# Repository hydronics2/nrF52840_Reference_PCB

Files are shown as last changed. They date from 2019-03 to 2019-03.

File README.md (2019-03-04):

# nrF52840_reference_PCB

This is a reference design for the nrF52840 for easy SWD programming and testing.  This layout uses the nrF52840 module from Raytek called the [MDBT50Q](http://www.raytac.com/upload/download_files/1bca545683ea4caf48e1ec796c09b9d9.pdf).
This PCB has been tested and it works!  This design relied heavily on the work of [Adafruit's feather board](https://www.adafruit.com/product/4062). I accidently ordered the -P1M version (PCB antenna). I think the -1M version chip antenna has slightly better range/performance.

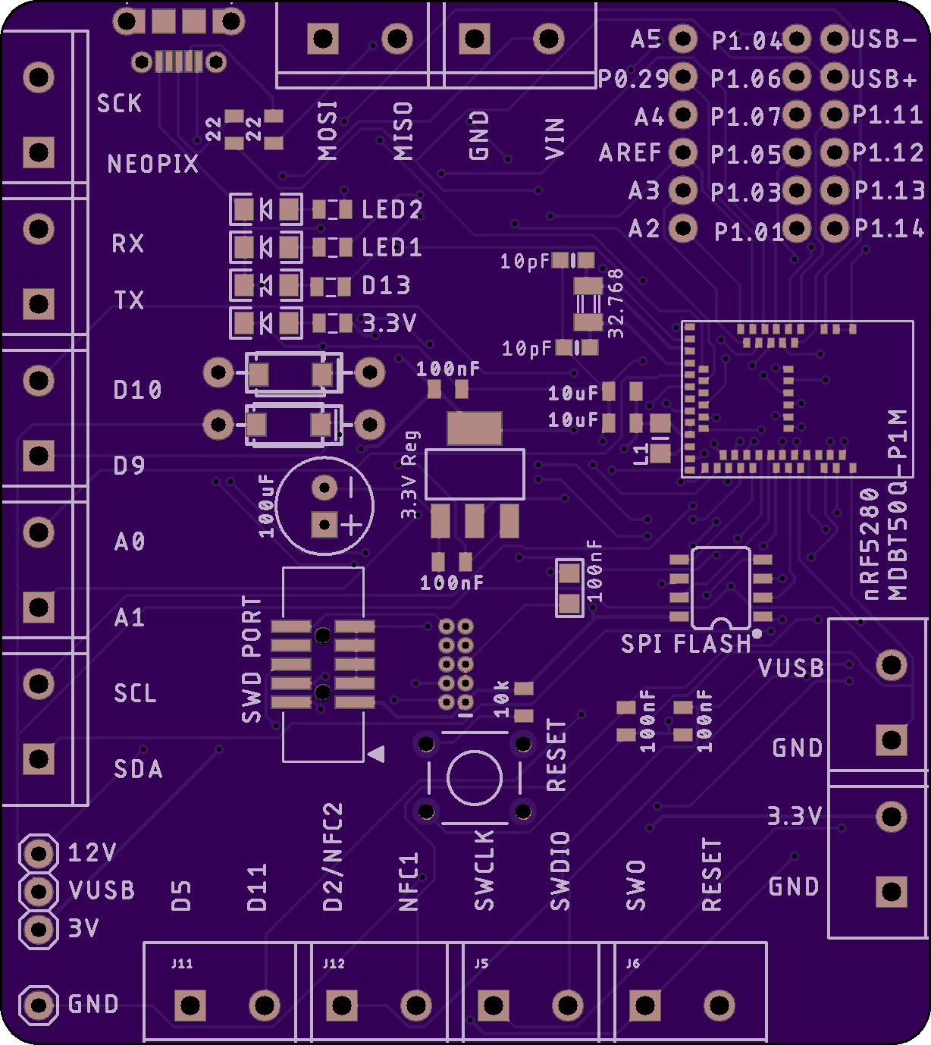
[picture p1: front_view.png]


I'm building an introduction class where I'd like to introduce students to soldering class, circuit python, and Internet of Things (IOT).  This module is also going to be a favorite for conference badges. This reference board is a good start. The changes from the feather are:
- broke out more pins
- changed the FLASH to an SOIC package
- changed some other packages slightly for easier soldering

You can order boards from Oshpark using this link: [project](https://oshpark.com/shared_projects/A5jKStz9).  

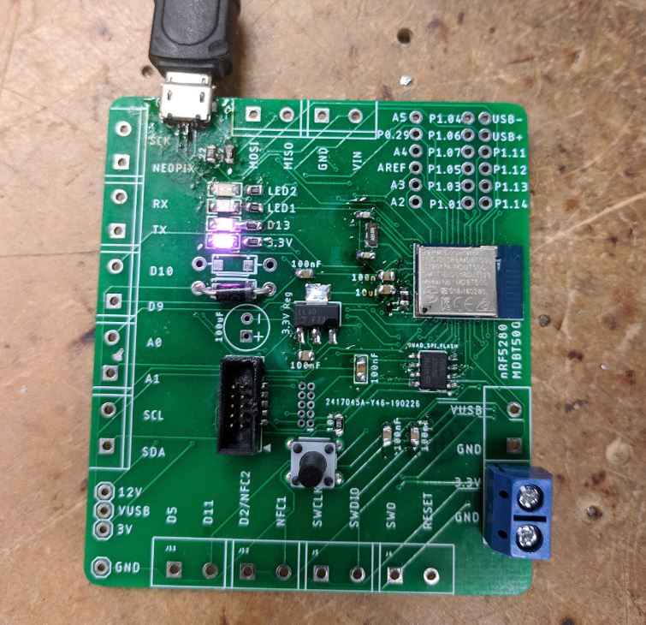
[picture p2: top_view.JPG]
project
This board has been tested and it works!! 

Here's a list of parts:

- MDBT50Q-P1M (PCB Antenna) from [digikey](https://www.digikey.com/product-detail/en/seeed-technology-co-ltd/113990583/1597-1679-ND/9697026). 
 or the MDBT50Q-1M (chip Antenna) from [digikey](https://www.digikey.com/product-detail/en/seeed-technology-co-ltd/113990584/1597-1680-ND/9697027)
- QUAD SPI Flash 2MB [digikey](https://www.digikey.com/product-detail/en/gigadevice-semiconductor-hk-limited/GD25Q16CTIGR/1970-1010-1-ND/9484760)
- 10 pin SWD Header from [digikey](https://www.digikey.com/product-detail/en/microchip-technology/ATSAMD21E15L-AFT/1611-ATSAMD21E15L-AFTCT-ND/6832779)
- 	Inductor 10UH  [digikey](https://www.digikey.com/product-detail/en/taiyo-yuden/LBR2012T100K/587-2045-1-ND/1788992)
- 3.3V Regulator (18V max input) [mouser](https://www.mouser.com/ProductDetail/511-LDL1117S50R)

- USB micro connector [digikey](https://www.digikey.com/product-detail/en/amphenol-icc-fci/10118194-0001LF/609-4618-1-ND/2785382)
- standard 6mmx6mm tactile RESET button [sparkfun](https://www.sparkfun.com/products/97)
- screw terminal 5mm pitch [sparkfun](https://www.sparkfun.com/products/8432) or [aliexpress](https://www.aliexpress.com/wholesale?catId=0&initiative_id=SB_20190221221755&SearchText=pcb+screw+terminal)
- input protection diodes on the 12V and USB input into the regulator. This is Adafruit's design. [digikey](https://www.digikey.com/product-detail/en/diodes-incorporated/B130-13-F/B130-FDICT-ND/815318)
- 32.768khz crystal (if needed, see above trinket design) [digikey](https://www.digikey.com/product-detail/en/epson/FC-135-32.7680KA-AG3/SER4086DKR-ND/6132726)
- crystal capacitors C7/C8 based on a 7pf load from the above crystal and assumed 2pf stray capacitence, CX1 = CX2 = 2(7pF - 2pF) = 10pF [digikey](https://www.digikey.com/product-detail/en/wurth-electronics-inc/885012006051/732-7793-1-ND/5454420)

SWD Programmer/Debugger: [Segger](https://www.digikey.com/product-detail/en/segger-microcontroller-systems/8.08.91-J-LINK-EDU-MINI/899-1061-ND/7387472)

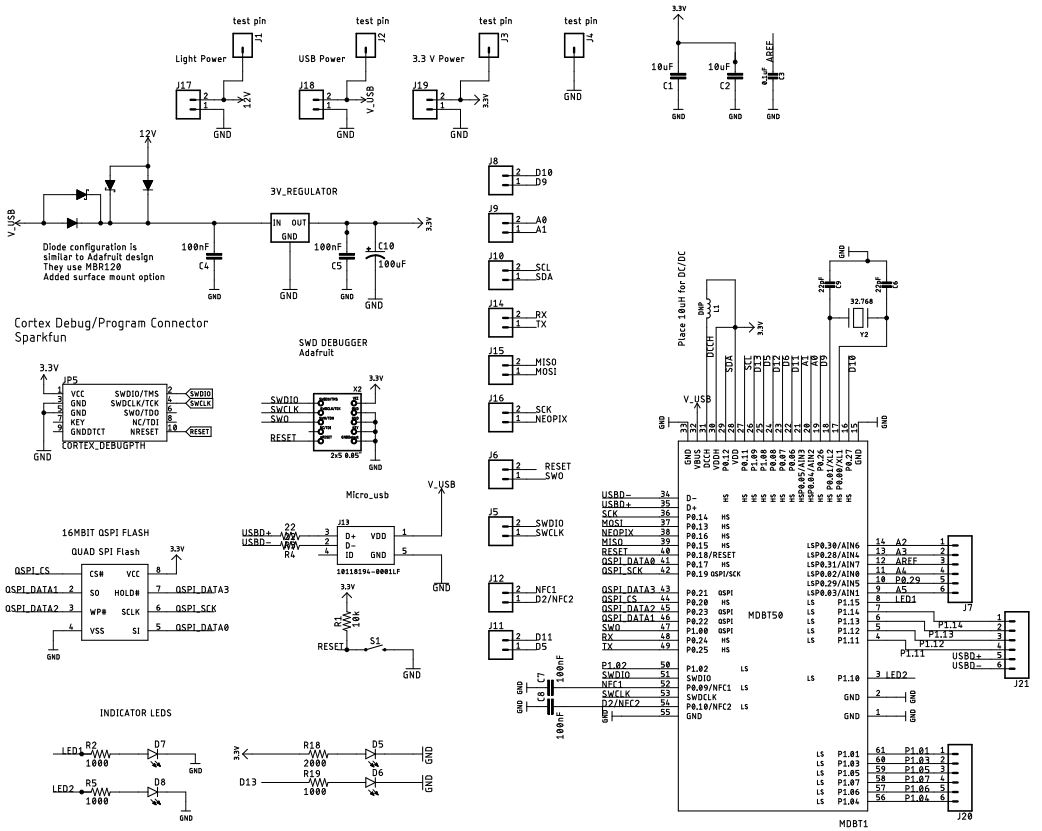
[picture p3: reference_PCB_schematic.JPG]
schematic


Notes:
- need to add a ground plane
- circuit python requires additional storage in the form of SPI Flash storage to hold files and libraries. For an extra $0.60 you can double to size of your flash to 4MB. Might be worth trying.

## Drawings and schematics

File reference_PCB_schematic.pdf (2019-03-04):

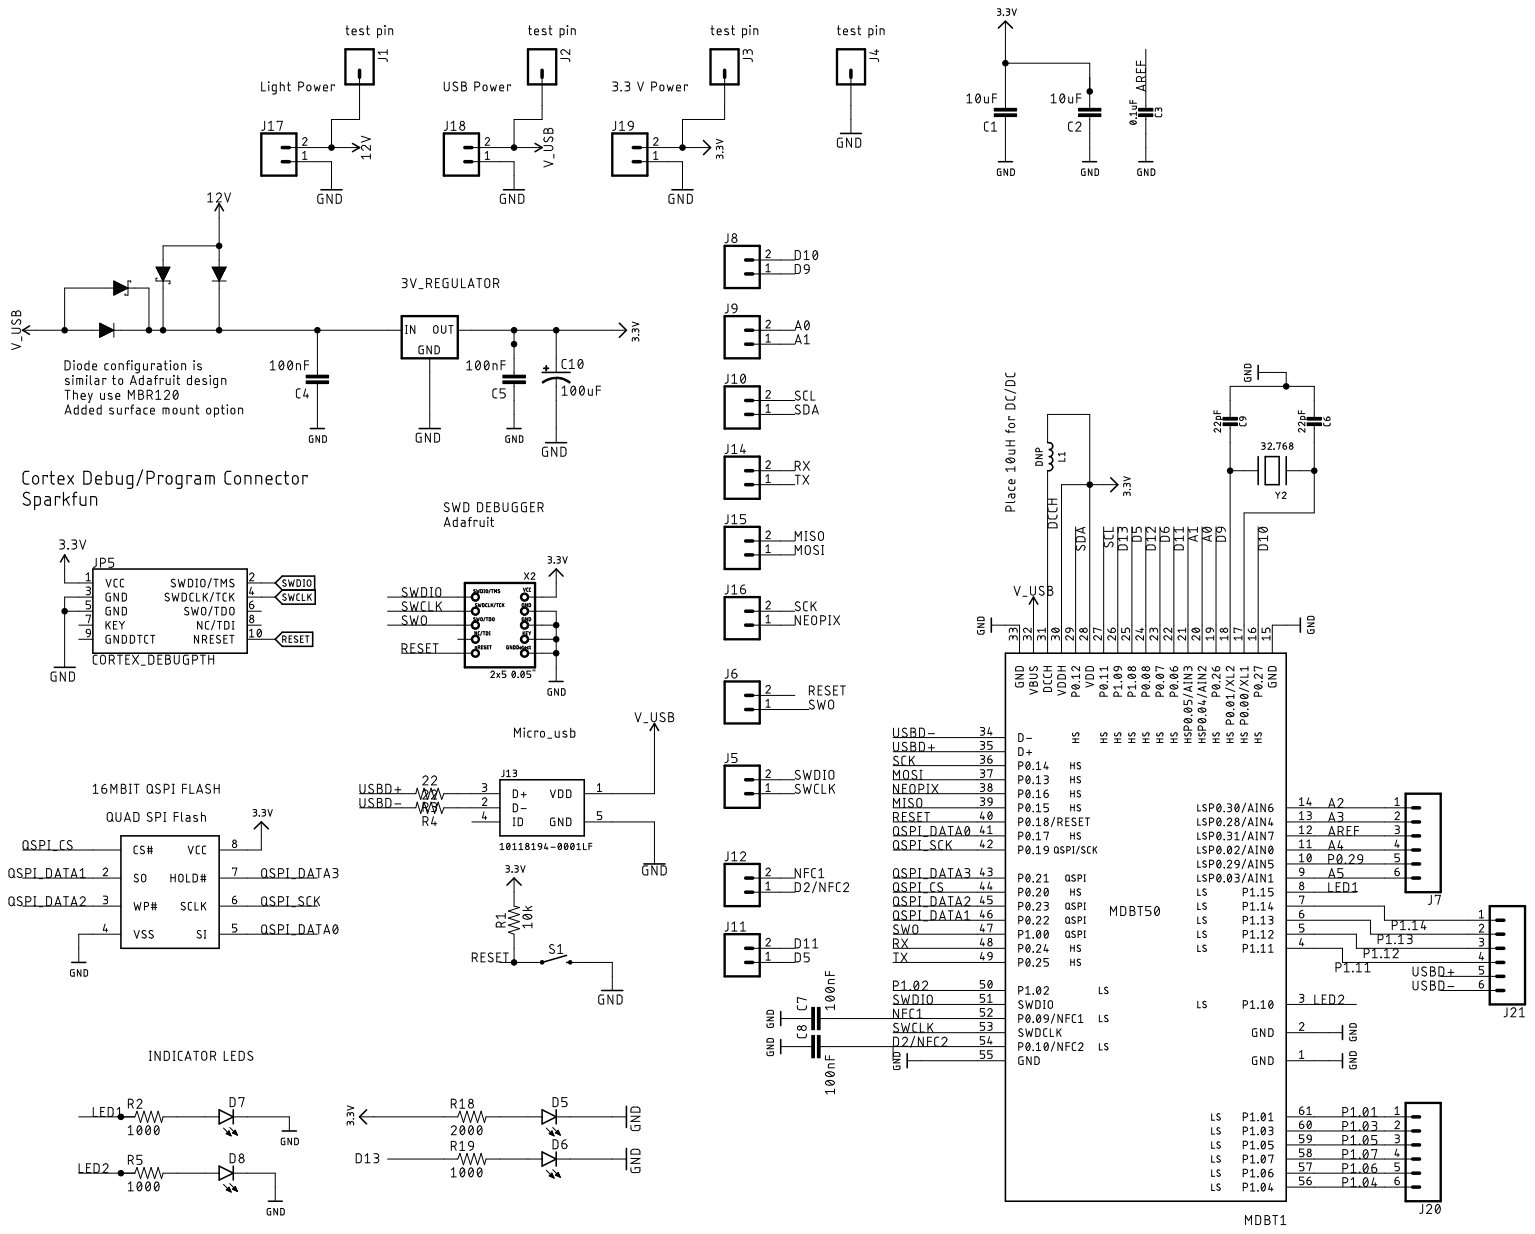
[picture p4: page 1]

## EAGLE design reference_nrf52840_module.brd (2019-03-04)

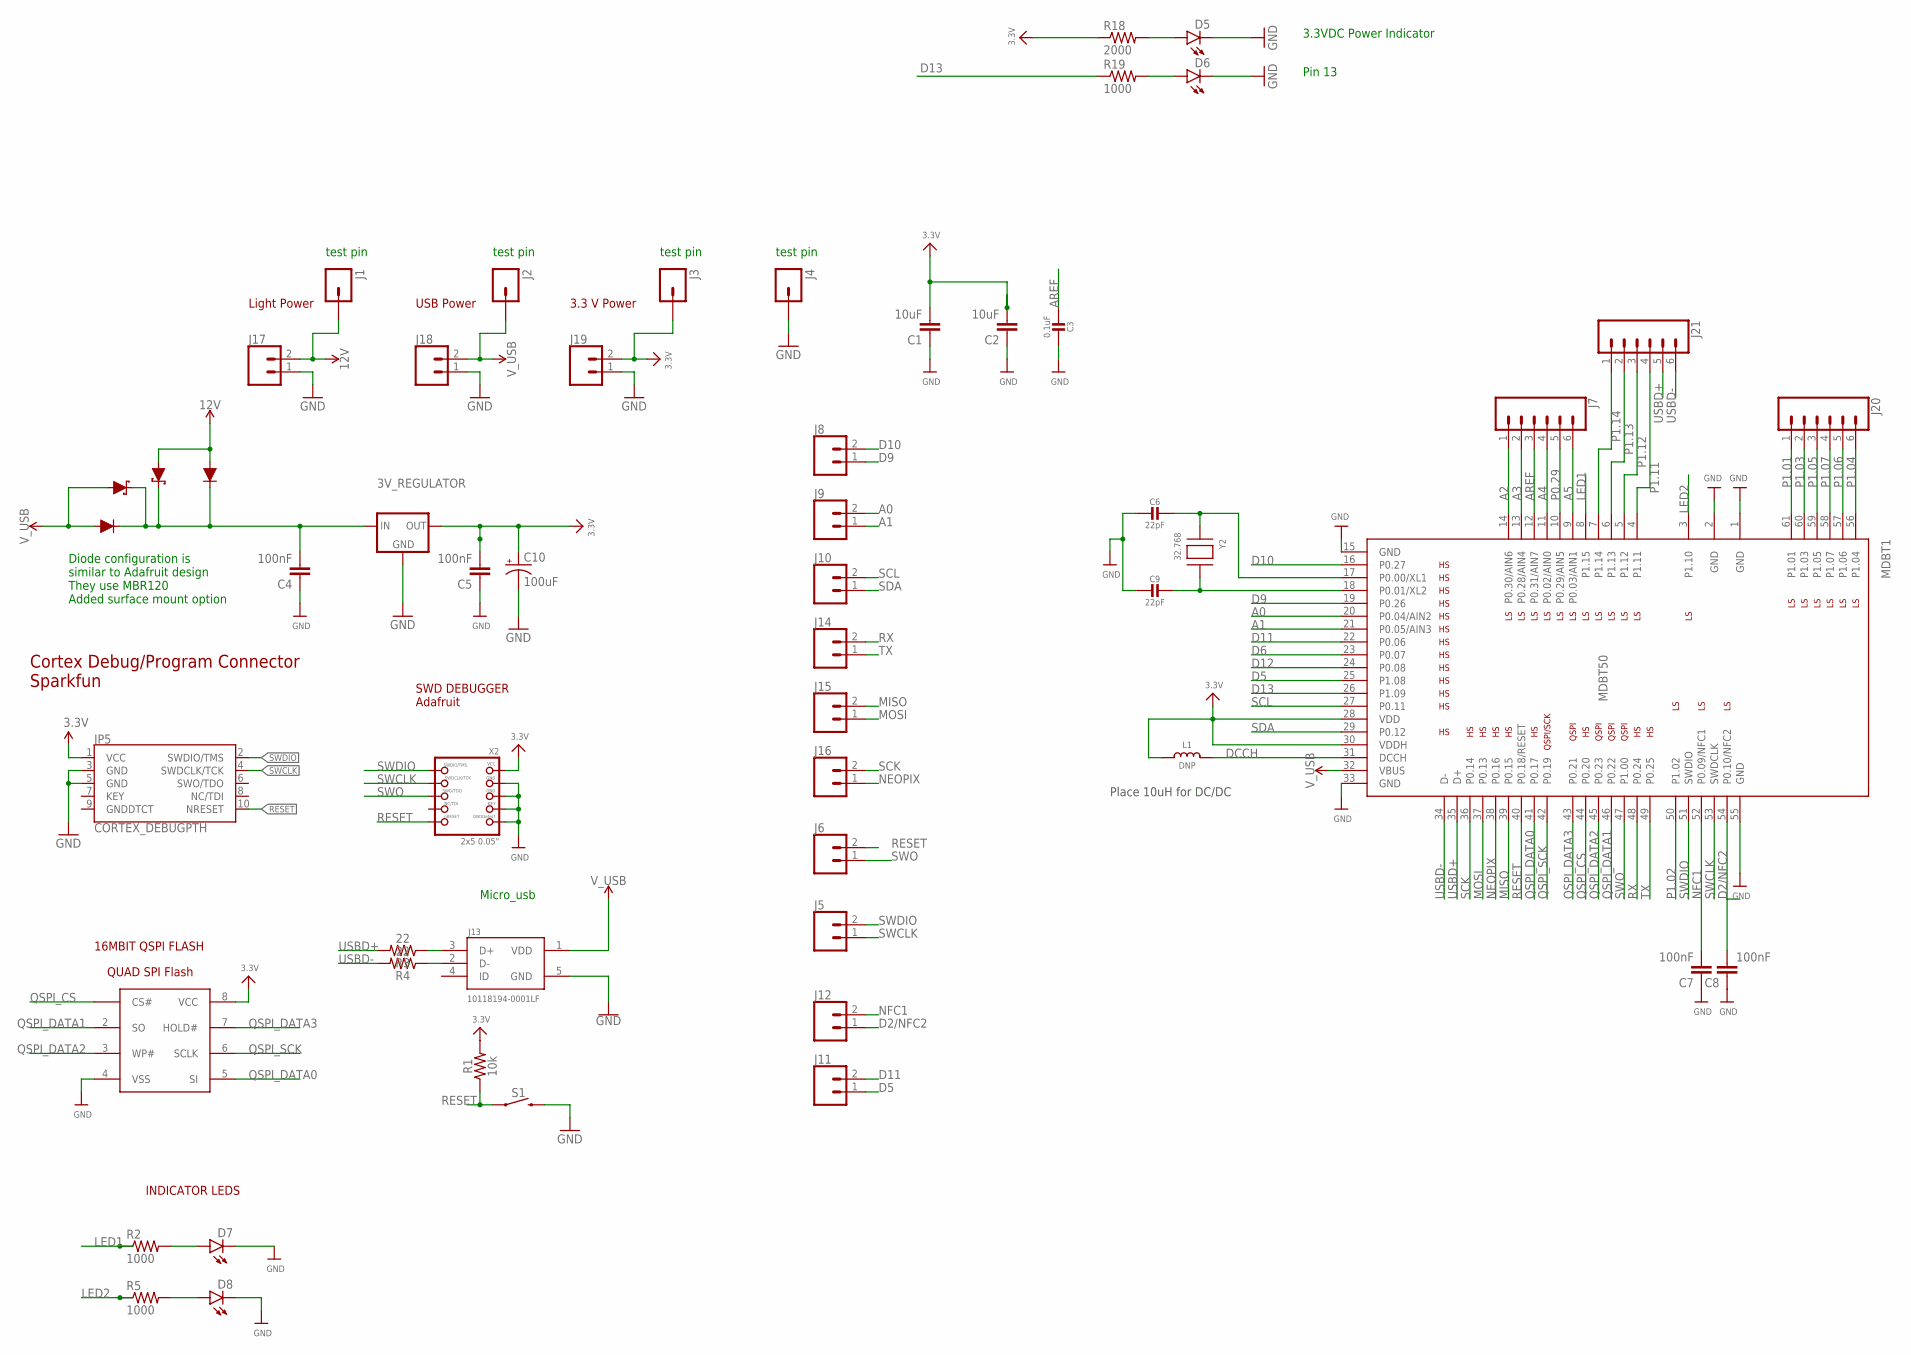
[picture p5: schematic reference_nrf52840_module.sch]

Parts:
3V_REGULATOR: LDL1117_5V_REG; SOT223
C1, C2: 10uF; 0805
C3: 0.1uF; _0805
C4, C5, C7, C8: 100nF; 0805
C6, C9: 22pF; 0603-NO
C10: 100uF; CPOL-RADIAL-2.5MM-6.5MM
D1, D2: 1A/50V/1.1V; DIODE-1N4001
D3, D4: 3A/40V/500mV; SMA-DIODE
D5, D6, D7, D8: LED1206; LED-1206
J1, J2, J3, J4: M01PTH; 1X01
J5, J6, J8, J9, J10, J11, J12, J14, J15, J16, J17, J18, J19: CONN_025MM; SCREWTERMINAL-5MM-2
J7, J20, J21: CONN_06NO_SILK_FEMALE_PTH; 1X06_NO_SILK
J13: 10118194-0001LF; FRAMATOME_10118194-0001LF
JP5: CORTEX_DEBUGPTH; 2X5-PTH-1.27MM
L1: DNP; _0805MP
MDBT1: MDBT50
R1: 10k; 0805
R2, R5, R19: 1000; 0805
R3, R4: 22; 0805
R18: 2000; 0805
S1: MOMENTARY-SWITCH-SPST-PTH-6.0MM-KIT; TACTILE_SWITCH_PTH_6.0MM_KIT
U$4: QUAD_SPI_FLASH; SO08
X2: 2x5 0.05"; 2X05_1.27MM_BOX_POSTS
Y2: 32.768; XTAL3215

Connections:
3.3V: 3V_REGULATOR.2 (OUT), 3V_REGULATOR.4 (OUT), C1.2, C2.2, C5.2, C10.1 (+), J3.1, J19.2, JP5.1 (VCC), L1.1, MDBT1.28 (VDD), MDBT1.30 (VDDH), R1.2, R18.1, U$4.8 (VCC), X2.1 (VCC)
12V: D1.A, D3.A, J1.1, J17.2
A0: J9.2, MDBT1.20 (P0.04/AIN2)
A1: J9.1, MDBT1.21 (P0.05/AIN3)
A2: J7.1, MDBT1.14 (P0.30/AIN6)
A3: J7.2, MDBT1.13 (P0.28/AIN4)
A4: J7.4, MDBT1.11 (P0.02/AIN0)
A5: J7.6, MDBT1.9 (P0.03/AIN1)
AREF: C3.2, J7.3, MDBT1.12 (P0.31/AIN7)
D2/NFC2: C8.2, J12.1, MDBT1.54 (P0.10/NFC2)
D5: J11.1, MDBT1.25 (P1.08)
D6: MDBT1.23 (P0.07)
D9: J8.1, MDBT1.19 (P0.26)
D10: J8.2, MDBT1.16 (P0.27)
D11: J11.2, MDBT1.22 (P0.06)
D12: MDBT1.24 (P0.08)
D13: MDBT1.26 (P1.09), R19.1
DCCH: L1.2, MDBT1.31 (DCCH)
GND: 3V_REGULATOR.1 (GND), C1.1, C2.1, C3.1, C4.1, C5.1, C6.2, C7.1, C8.1, C9.2, C10.2 (-), D5.C, D6.C, D7.C, D8.C, J4.1, J13.5 (GND), J17.1, J18.1, J19.1, JP5.3 (GND), JP5.5 (GND), MDBT1.1 (GND), MDBT1.2 (GND), MDBT1.15 (GND), MDBT1.33 (GND), MDBT1.55 (GND), S1.3 (2), U$4.4 (VSS), X2.3 (GND), X2.5 (GND), X2.7 (KEY), X2.9 (GNDDETECT)
LED1: MDBT1.8 (P1.15), R2.1
LED2: MDBT1.3 (P1.10), R5.1
MISO: J15.2, MDBT1.39 (P0.15)
MOSI: J15.1, MDBT1.37 (P0.13)
unnamed: D7.A, R2.2
unnamed: J13.3 (D+), R3.1
unnamed: J13.2 (D-), R4.1
unnamed: 3V_REGULATOR.3 (IN), C4.2, D1.C, D2.C, D3.C, D4.C
unnamed: C9.1, MDBT1.18 (P0.01/XL2), Y2.P$2
unnamed: C6.1, MDBT1.17 (P0.00/XL1), Y2.P$1
unnamed: D8.A, R5.2
unnamed: D5.A, R18.2
unnamed: D6.A, R19.2
NEOPIX: J16.1, MDBT1.38 (P0.16)
NFC1: C7.2, J12.2, MDBT1.52 (P0.09/NFC1)
P0.29: J7.5, MDBT1.10 (P0.29/AIN5)
P1.01: J20.1, MDBT1.61 (P1.01)
P1.02: MDBT1.50 (P1.02)
P1.03: J20.2, MDBT1.60 (P1.03)
P1.04: J20.6, MDBT1.56 (P1.04)
P1.05: J20.3, MDBT1.59 (P1.05)
P1.06: J20.5, MDBT1.57 (P1.06)
P1.07: J20.4, MDBT1.58 (P1.07)
P1.11: J21.4, MDBT1.4 (P1.11)
P1.12: J21.3, MDBT1.5 (P1.12)
P1.13: J21.2, MDBT1.6 (P1.13)
P1.14: J21.1, MDBT1.7 (P1.14)
QSPI_CS: MDBT1.44 (P0.20), U$4.1 (CS#)
QSPI_DATA0: MDBT1.41 (P0.17), U$4.5 (SI)
QSPI_DATA1: MDBT1.46 (P0.22), U$4.2 (SO)
QSPI_DATA2: MDBT1.45 (P0.23), U$4.3 (WP#)
QSPI_DATA3: MDBT1.43 (P0.21), U$4.7 (HOLD#)
QSPI_SCK: MDBT1.42 (P0.19), U$4.6 (SCLK)
RESET: J6.2, JP5.10 (NRESET), MDBT1.40 (P0.18/RESET), R1.1, S1.1, X2.10 (NRESET)
RX: J14.2, MDBT1.48 (P0.24)
SCK: J16.2, MDBT1.36 (P0.14)
SCL: J10.2, MDBT1.27 (P0.11)
SDA: J10.1, MDBT1.29 (P0.12)
SWCLK: J5.1, JP5.4 (SWDCLK/TCK), MDBT1.53 (SWDCLK), X2.4 (SWDCLK)
SWDIO: J5.2, JP5.2 (SWDIO/TMS), MDBT1.51 (SWDIO), X2.2 (SWDIO)
SWO: J6.1, MDBT1.47 (P1.00), X2.6 (SWO)
TX: J14.1, MDBT1.49 (P0.25)
USBD+: J21.5, MDBT1.35 (D+), R3.2
USBD-: J21.6, MDBT1.34 (D-), R4.2
V_USB: D2.A, D4.A, J2.1, J13.1 (VDD), J18.2, MDBT1.32 (VBUS)

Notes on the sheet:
SWD DEBUGGER Adafruit
Cortex Debug/Program Connector Sparkfun
Micro_usb
Light Power
USB Power
3.3 V Power
Diode configuration is similar to Adafruit design They use MBR120 Added surface mount option
3.3VDC Power Indicator
Pin 13
test pin
Place 10uH for DC/DC
16MBIT QSPI FLASH
INDICATOR LEDS

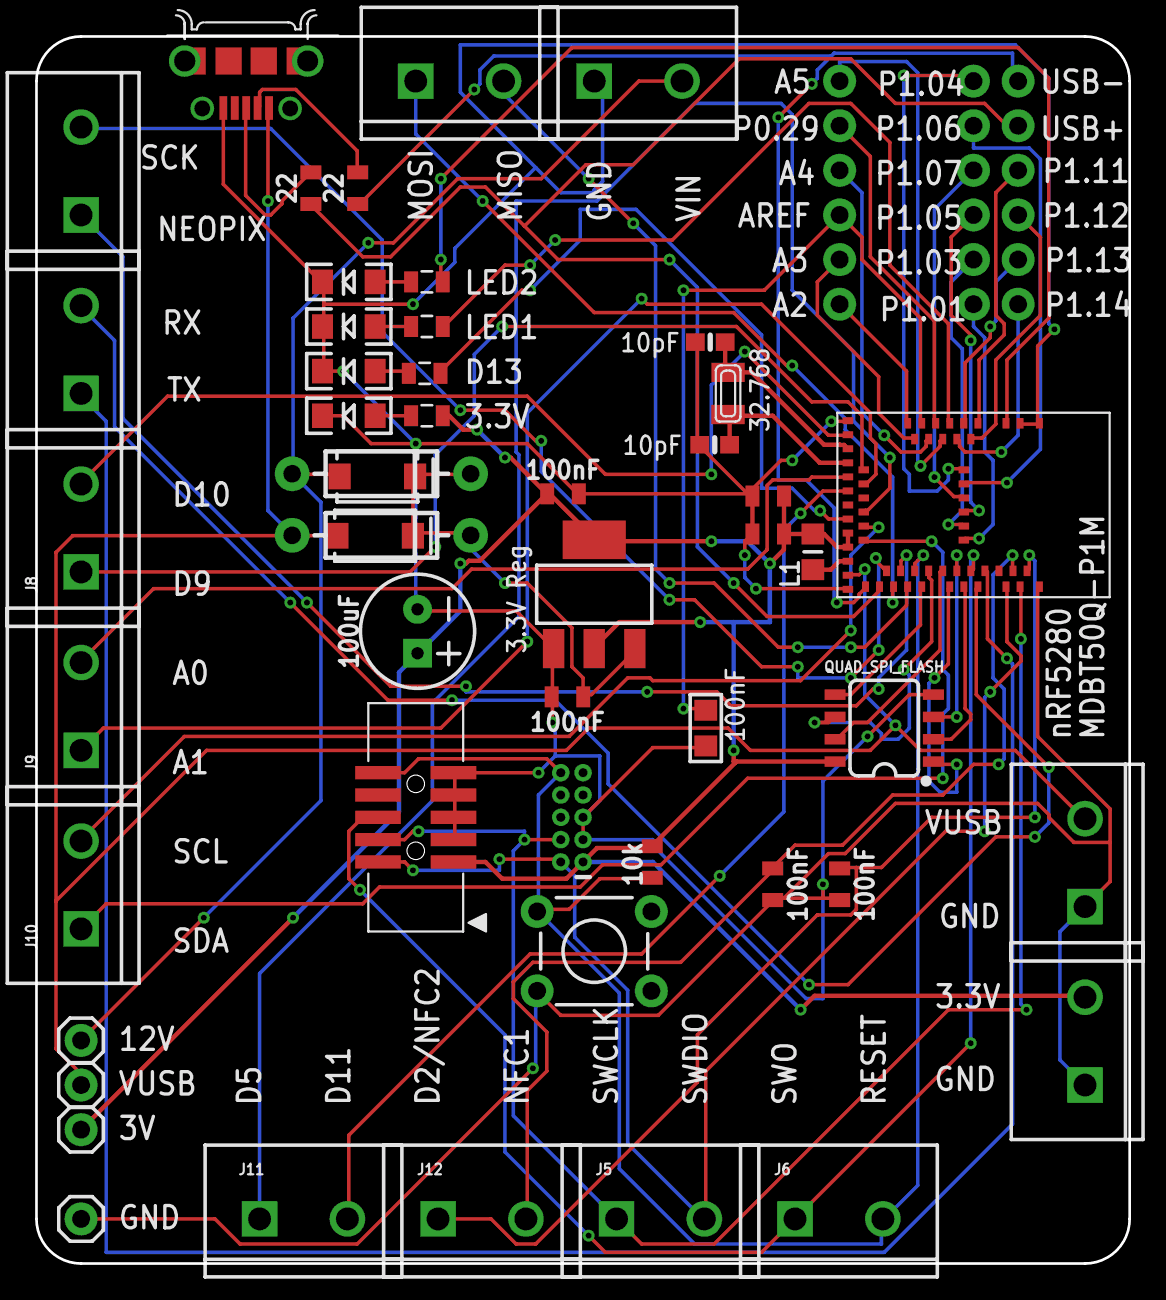
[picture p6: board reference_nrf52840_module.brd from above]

Board: 2 copper layers, 62.2 x 69.9 mm, 54 parts (0 on the bottom side), 61 nets.

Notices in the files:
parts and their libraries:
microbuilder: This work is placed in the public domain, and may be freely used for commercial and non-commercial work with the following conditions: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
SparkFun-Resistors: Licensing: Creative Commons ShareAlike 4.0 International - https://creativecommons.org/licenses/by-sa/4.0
